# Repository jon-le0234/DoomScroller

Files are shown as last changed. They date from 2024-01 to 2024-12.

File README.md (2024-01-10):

# DoomScroller
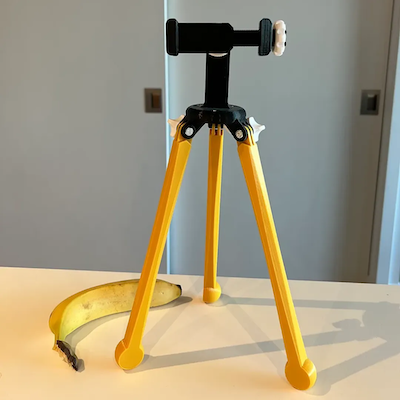
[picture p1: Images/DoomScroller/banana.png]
DoomScroller smartphone tripod holding an iPhone Pro Max in landscape

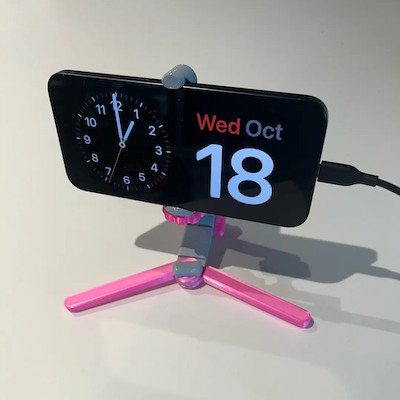
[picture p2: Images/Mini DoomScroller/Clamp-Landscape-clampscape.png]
Mini DoomScroller smartphone tripod holding an iPhone Pro Max in landscape, showing iOS 17 StandBy


A 3D-printed smartphone tripod and harm reduction tool for doomscrolling, designed with accessibility in mind.

# Overview
Originally designed for use during the COVID pandemic lockdowns, the DoomScroller and Mini DoomScroller are tripods for securely mount devices like smartphones, tablets, GoPros, and other rectangular prism objects.

[][cc-by-nc]

[][cc-by-nc]

[cc-by-nc-shield]: https://img.shields.io/badge/License-CC%20BY%204.0-lightgrey.svg
[cc-by-nc]: http://creativecommons.org/licenses/by-nc/4.0/
[cc-by-nc-image]: https://i.creativecommons.org/l/by-nc/4.0/88x31.png

## Features
1. Open source 3D model
    1. Remixed [popular, proven designs](#origin-story) on Thingiverse.
    1. Made in [OnShape CAD](https://cad.onshape.com/documents/ee0d92fdf6736f8a494244af/w/14bbf8e148085a817d797314/e/513b945eaf0116b0d17e9980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) free plan, which requires that models be shared openly.
1. Wider applications than traditional tripods and stands for electronic devices
    1. Ball joint enables wider viewing angles and orientations.
    1. Adjustable legs allow for use on uneven surfaces, such as beds, couches, and reclining chairs.
1. Portable
    1. The Mini DoomScroller folds up into a small size that can fit into a small purse, large pocket, or backpack.
1. 3D-printed
    1. Customizable design
        1. Unlike commercial, off-the-shelf smartphone tripods and stands, the DoomScroller can be printed in all your favourite colours.
        1. [Custom fastener threads](https://forum.onshape.com/discussion/4867/new-featurescript-thread-creator)
    1. Environmentally friendly
        1. Get a custom tripod without requiring a manufacturer to mass-produce and distribute a generic product.
        1. Modular design makes the DoomScroller easy to assemble, repair, and upgrade.
1. Actively developed
    1. I'm constantly pursuing a better design because I currently use the DoomScroller on a daily basis.
    1. Taking feature requests.
        1. My friend asked if I could make the DoomScroller more portable for their travels, so the Mini DoomScroller was born.
        1. GoPro functionality was requested by a user on Printables.
1. Parametric, one day
    1. Generate a custom clamp with a parametric model, once I finish the OpenSCAD design.

## Use Cases
The DoomScroller and Mini DoomScroller can be used in many applications.
1. Read social media on your smartphone in bed.
1. Watch video on your own device on a plane's tray table.
1. Join video conferencing calls like Zoom (ZoomScroller).
1. Record video where other tripods are too bulky to pack.
1. Charge your smartphone with MagSafe.
1. Use StandBy with iOS 17 on your bedside table.
1. Pair with a PanaVise [305](http://panavise.com/index.html?pageID=1&page=full&--eqskudatarq=12) or [300](http://panavise.com/index.html?pageID=1&page=full&--eqskudatarq=532) base to provide 360º horizontal rotation and 90º vertical tilt, and use with other compatible PanaVise products, like [circuit board holders](http://panavise.com/index.html?pageID=1&page=full&--eqskudatarq=24).
1. Record video on a GoPro.

Print one and give it to someone in need!

I originally hosted these two projects in Thingiverse and Printables, but it became too much work to update all four pages during active development. Thus, this documentation is meant to keep me on track. I hope that moving to Github will also make it easier for future users who can't make sense of my incomplete instructions across the original project pages.

## What is doomscrolling?
[Doomscrolling](https://en.wikipedia.org/wiki/Doomscrolling), or doomsurfing, is the act of spending an excessive amount of screen time devoted to the absorption of negative news.

I took a harm reduction approach. People are probably going to be doomscrolling anyways, so you may as well try to keep yourself safe while you're at it. No need to hurt your hands, neck, or eyes if you don't have to.

## Origin Story
During one of several COVID-19 lockdowns in 2020, I started to feel some strain in my hands and neck from scrolling all of the social media timelines on my smartphone. There was nowhere to go, nobody to visit, vaccines still being developed, all a person could do during the winter months was to escape into their smartphone for work and personal reasons.

There were already some fine mounting and tripod projects on Thingiverse, so I remixed them.
- [Tripod Phone Stand (no screw ! )](https://www.thingiverse.com/thing:4694593)
- [Modular Mounting System](https://www.thingiverse.com/thing:2194278)
- [Open Source Universal Ball Joint (to reuse!)](https://www.thingiverse.com/thing:4739696)

# Getting Started
Choose your style of DoomScroller:
1. [DoomScroller](#1-doomscroller)
1. [Mini DoomScroller](#2-mini-doomscroller)

Here is a brief comparison of the tradeoffs:
| Feature | DoomScroller | Mini DoomScroller |
| --- | --- | --- |
| Edition | Original | Newer |
| Location | Home | Data |
| Size | Bigger | Smaller |
| Materials | Plastic and metal | Plastic |
| Print Time (Prusa MK3S) | ~6.5 hours (150 mm legs) | ~3 hours |

# 1. DoomScroller
## Print Instructions
1. Pick a length for your DoomScroller's legs.
    - Either 150 mm (file 1a) or 220 mm (file 1b).
    - I'm 5'10" (178 cm) tall, and I prefer the 220 mm legs myself.
1. Pick a mounting style.
    1. Most users will need the Frame (file 7b).
        1. Frame also requires printing of Frame lock (file 8) and Frame screw (file 9).
    1. iPhone 12 and newer may want to use the MagFace (file 7a).
        1. MagFace also requires an Apple MagSafe charger.

CAUTION: Clamping too tightly on your device can break it; apparently plastic threads can be pretty strong. I take no responsibility for broken devices, but I have designed clamps that prevent damage by limiting the amount of threading.

To get a better sense of the smartphone use case, I made a table of physical dimensions of popular smartphones (Device sizes.csv). Still a work in progress, but sharing if it'll be useful to others.

### Non-3D-Printed Parts Required
1. Three (3) of M3x8 mm socket head cap screws
1. Three (3) of M3 hex nuts
1. Three (3) of M5x20mm hex bolt
1. Three (3) of M5 hex nuts

## Colour Schemes
You can do whatever you want here, truly, but files are organized for a two-tone colourway.
1. Dominant colours
    1. Legs (1ab)
    1. Hip (2)
    1. Neck (3)
    1. Ball Joint split (5)
    1. MagFace (7a)
    or
    1. Frame base (7b)
        1. Frame lock (8)
1. Accent colours
    1. Knob (4)
    1. Ball Joint screw (6)
    1. Frame screw (7b).

### Logos
Consider how many colours are used and how much area each one takes in the overall image. Usually there will be one or two dominant colours, and then some accent colours. You can even get different colours for the screws and nuts.
- Dominant colours: Legs, Neck, Hip, Frame Base, Frame Lock.
- Accent colours: Hip, Knob, Ball Joint Screw, Frame Screw, metal screws.

See the example photo of the Edmonton Oilers' McDavid jersey with an older prototype I made for a friend. I got lucky with this logo because of the oil derrick structure and orange oil drop look created by the ball joint.

## DoomScroller Assembly
See DoomScroller/Images/##.webp for visual assembly instructions.

# 2. Mini DoomScroller
## Print Instructions
Users have a few options for simple or semi-custom prints:
1. Mounting style
1. Amount of threading
1. Device width
1. Device depth

### Simple
1. Open plate file in PrusaSlicer as project to preserve the painted-on support settings.
    1. Mini DoomScroller - Clamp - Full Plate w100 x d15.3mf
    1. Mini DoomScroller - Clamp - Accent Colour.3mf
1. [Assemble](#mini-doomscroller-assembly).

### Semi-Custom
1. Select mounting style.
    1. MagFace
    1. GoPro
    1. Clamp
1. Assemble.

For clamp mounting, decide whether you want a general or single size.
1. General size
    1. Uses a longer thread, allowing for devices of multiple widths and depths.
    1. Good for using DoomScrollers with devices of different sizes, e.g., sharing with other users.
1. Single size
    1. Has a shorter thread, allowing for devices of fewer widths and depths.
    1. Good for preventing damage to devices.
    1. Good for personal use and sharing with other devices of similar size.
    1. Currently only some combinations of widths and depths are available.
1. I'm working on a parametric OpenSCAD model for the clamp. Not ready yet.
    1. This model will allow for even further customization, such as with the Thingiverse Customizer.
        
## Mini DoomScroller Assembly
See "Mini DoomScroller/Images/##.webp" files to follow along with assembly instructions.

2024-01-02: Filenames in below instructions need to be updated.

1. Insert torso.3mf and neck.3mf so that hinges are flush on both sides.
1. Insert hip-bolt.3mf into the unthreaded side of the hinge, then screw into the M12 thread of neck.3mf to tighten hinge.
1. Place ball.3mf into the spherical section in neck.3mf.
1. Place ball-joint-nut.3mf over ball.3mf, and screw onto the M22 thread of neck.3mf to tighten.
1. Screw the selected mount into the M12 thread of ball.3mf.
1. If using magface.3mf, skip to step 9.
1. Insert clamp-movable-jaw.3mf over clamp-frame.3mf.
1. Screw clamp-nut.3mf onto the M15 thread of Clamp frame.3mf.
1. Place left-leg-threaded.3mf on the underside of the joint on torso.3mf. It will sit between torso.3mf and neck.3mf when folded.
1. Place right-leg.3mf on the opposite side of the torso joint.
1. (Optional) Use leg-bolt-washer.3mf on top of right-leg.3mf. This adds length for leg-bolt.3mf, and adds another option for mixing colours.
1. Insert leg-bolt.3mf through right-leg.3mf and screw into M12 thread of left-leg.3mf.
1. It is finished! 

## Print Recommendations
### Colours
You can choose whichever colour scheme you like! I’ve printed Mini DoomScrollers in monochrome, two-tone, and rainbow.

Found the two-tone to be received best by beta testers, so I’ve organized the files into folders “Main Colour” and “Accent Colour.”

### Materials
PLA and PETG work great!

PETG is a little bouncier.

## Supports
I set the following PrusaSlicer settings for easier removal of supports (see screenshot in gallery):

1. Snug for “Style” is better than Organic for this model.
1. 90º for “Pattern angle” exposes the snug supports' folds.
1. 0.3 mm for both “Top contact Z distance” and “Bottom contact Z distance.
1. 2 layers for both “Top interface layers” and “Bottom interface layers.”

## Additional Considerations
1. OnShape link for intrepid users that want to customize the design further: [Mini DoomScroller](https://cad.onshape.com/documents/ee0d92fdf6736f8a494244af/w/14bbf8e148085a817d797314/e/513b945eaf0116b0d17e9980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)
    1. Requires an OnShape account.
    1. Create a copy of the design.
    1. Customize to your heart's content.
1. Ball joint uses an M12 thread with 1.5 mm pitch.
1. Clamp screw, hip bolt, and leg bolt use an M15 thread with 1.5 mm pitch.

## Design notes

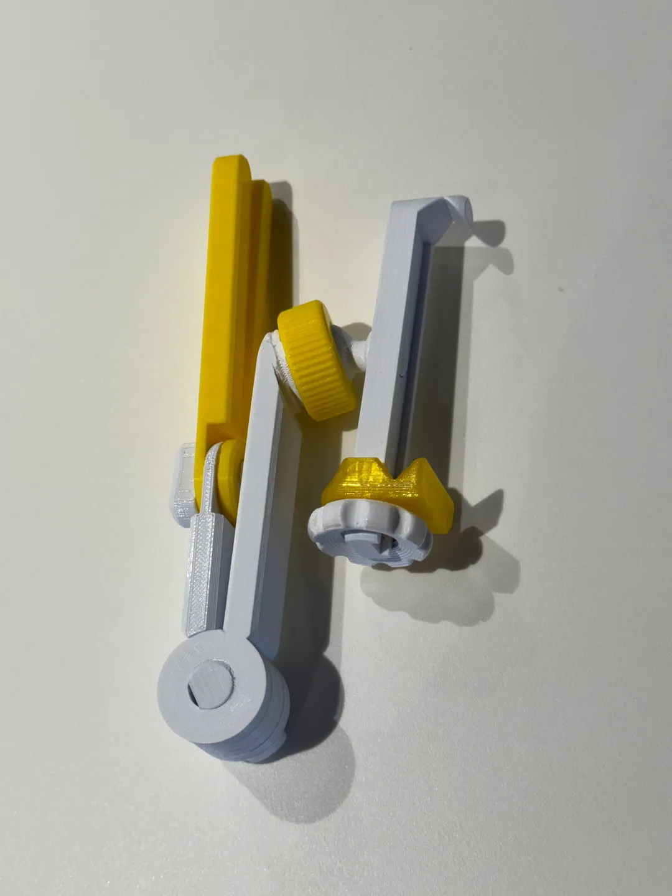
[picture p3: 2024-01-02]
Images/Mini DoomScroller/clamp-folded.png

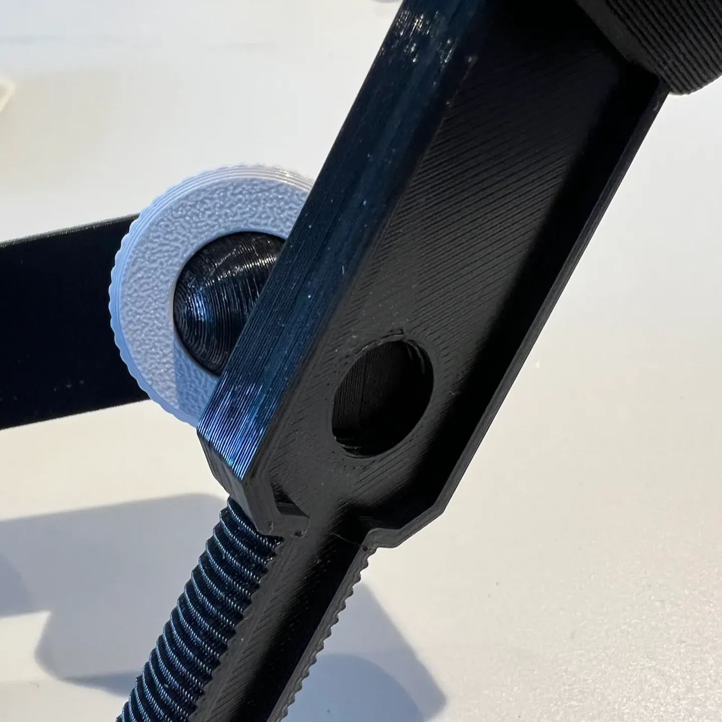
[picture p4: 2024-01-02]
Images/DoomScroller/15b.png

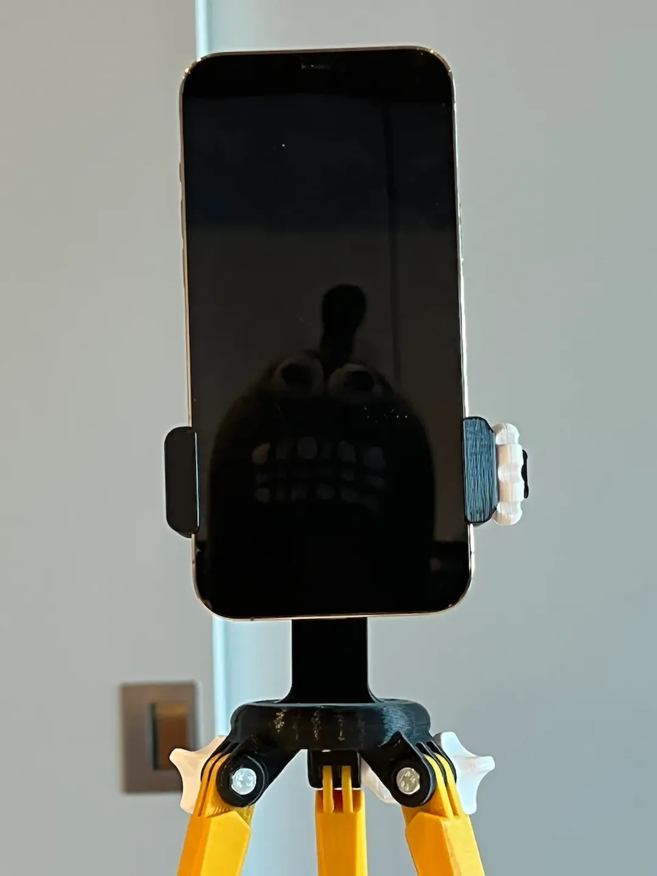
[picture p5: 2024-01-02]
Images/DoomScroller/portrait.png

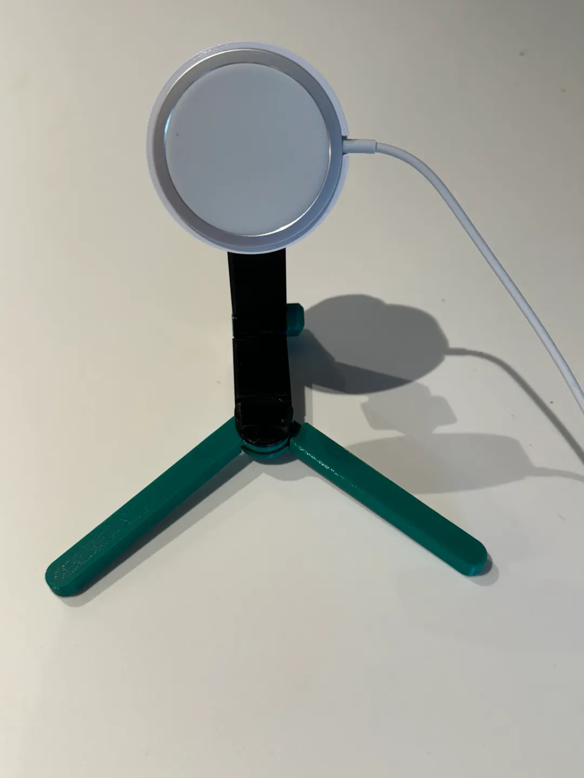
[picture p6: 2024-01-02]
Images/Mini DoomScroller/magface.png

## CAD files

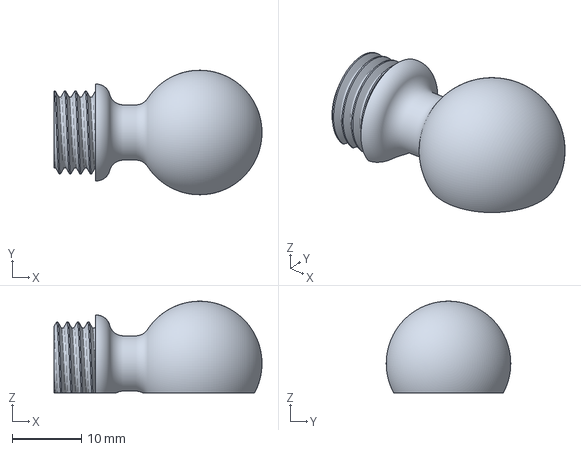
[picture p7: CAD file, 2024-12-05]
3D-Models/Ball.3mf
30.1 x 18.0 x 13.2 mm

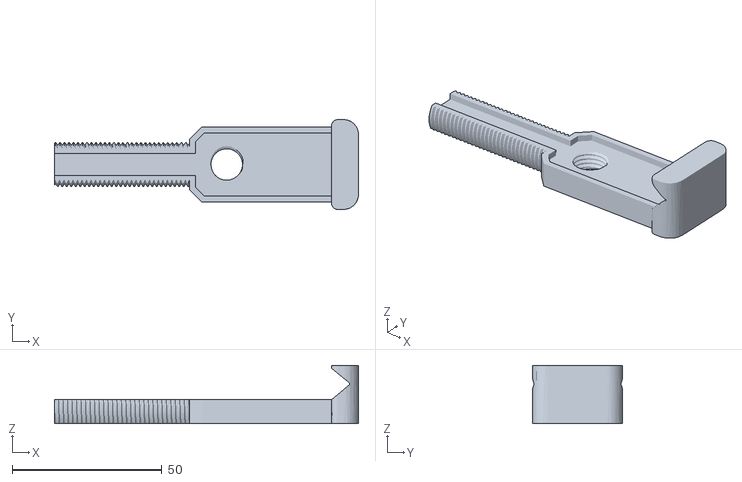
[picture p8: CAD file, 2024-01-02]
3D-Models/Common-Components/Mounts/Clamps/7c DoomScroller - Frame base (original).stl
101.5 x 30.0 x 19.5

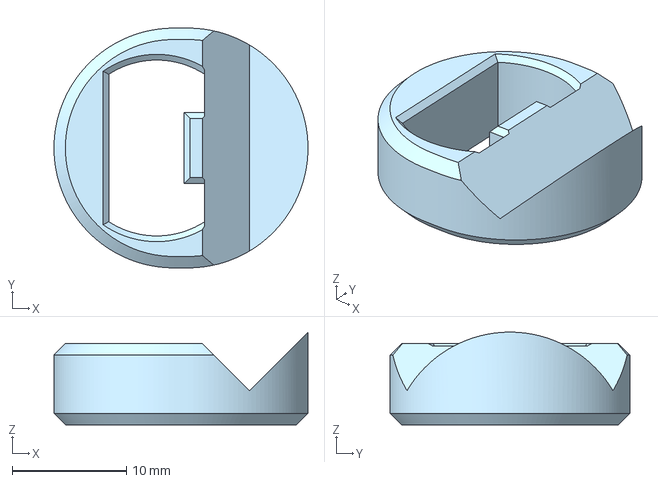
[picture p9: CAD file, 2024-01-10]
3D-Models/Common-Components/Mounts/Clamps/Smartphones/Mini DoomScroller - Clamp movable jaw iPhone 15 Pro Max.3mf
22.2 x 21.0 x 8.12 mm

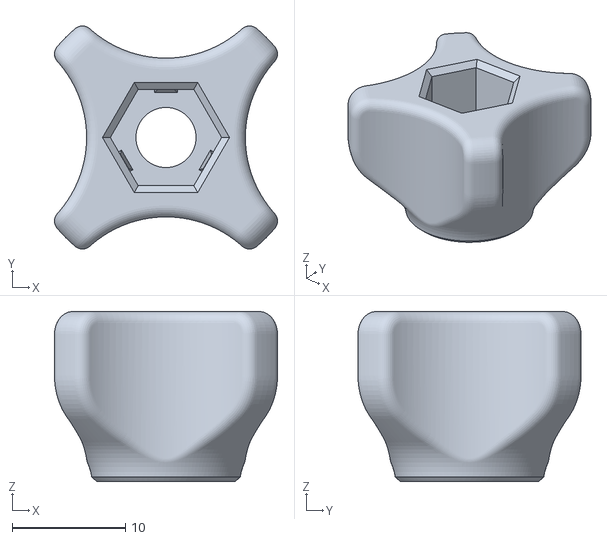
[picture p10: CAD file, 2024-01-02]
3D-Models/DoomScroller/DoomScroller - Knob.stl
19.7 x 19.7 x 15.0

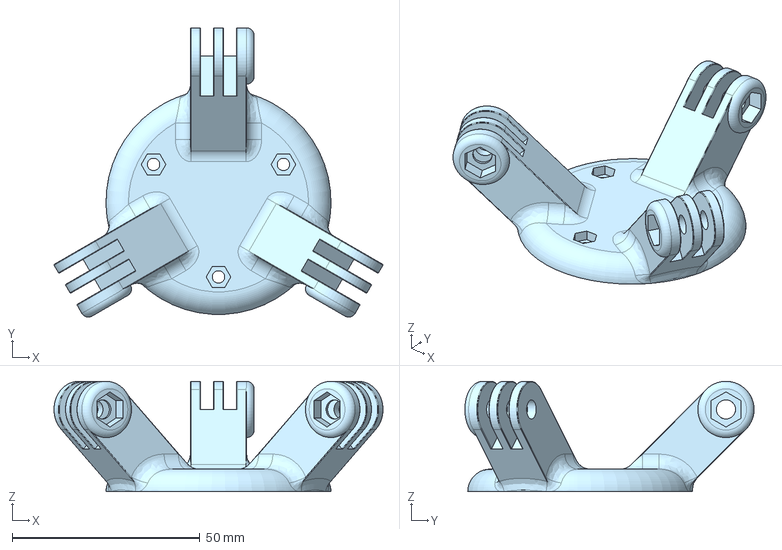
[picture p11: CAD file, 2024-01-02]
3D-Models/DoomScroller/Hips/2a DoomScroller - Hip.step
87.7 x 77.1 x 29.4 mm

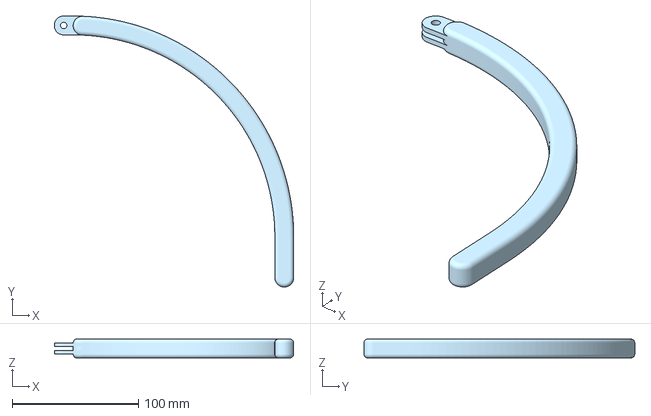
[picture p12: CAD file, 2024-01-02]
3D-Models/DoomScroller/Legs/1d DoomScroller - Leg, Curved 160 + 40.3mf
190.0 x 215.0 x 15.0 mm

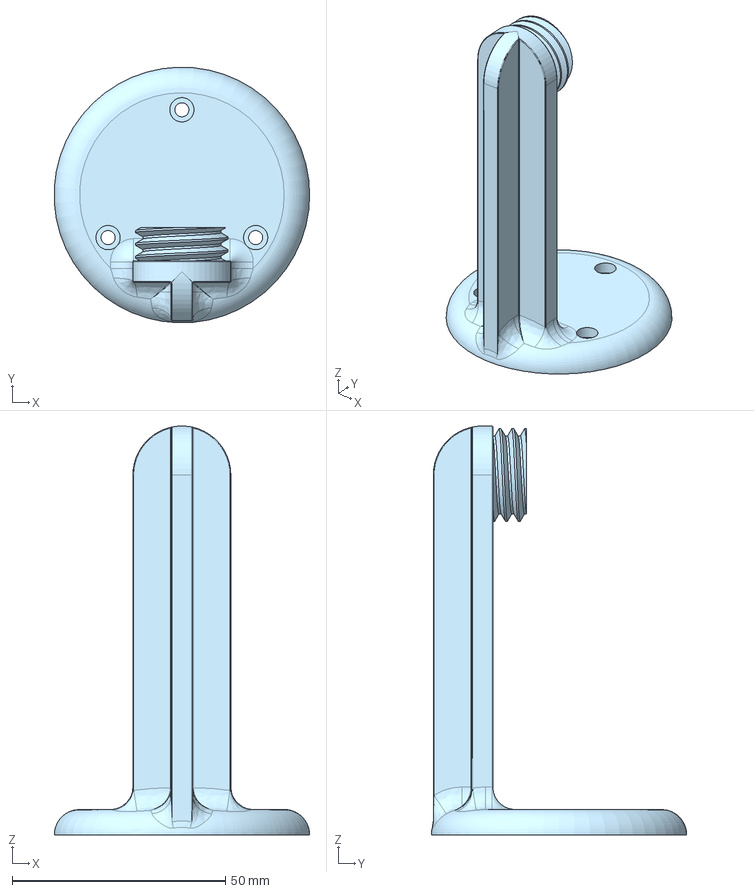
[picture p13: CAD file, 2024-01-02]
3D-Models/DoomScroller/Necks/3a DoomScroller - Neck.step
59.9 x 60.0 x 96.0 mm

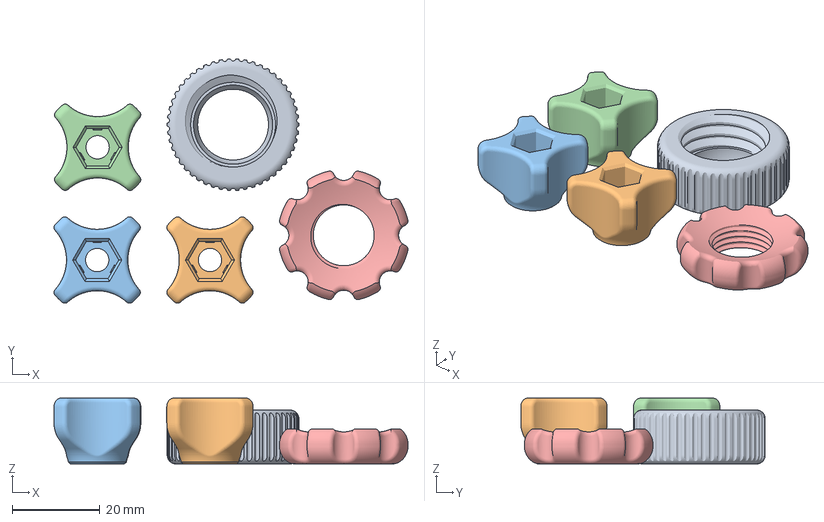
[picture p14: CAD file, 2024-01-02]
3D-Models/DoomScroller/Plates/DoomScroller-Accent-Colour.3mf
80.6 x 55.6 x 15.0 mm
6 DoomScroller - Ball Joint Screw.stl
4 DoomScroller - Knob.stl
9 DoomScroller - Frame screw.stl

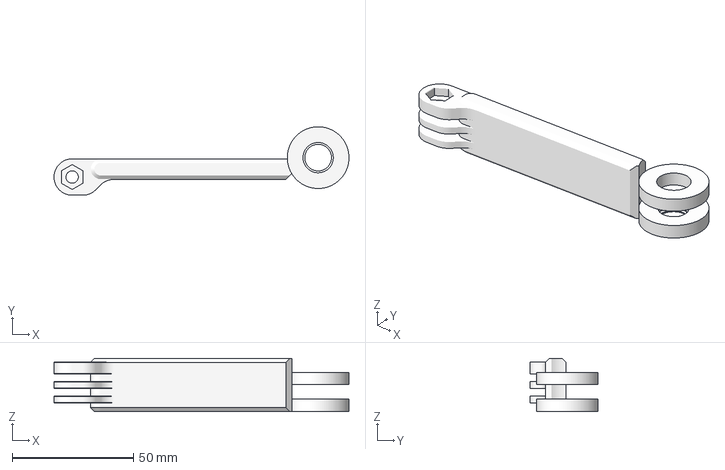
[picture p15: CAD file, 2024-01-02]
3D-Models/Mini DoomScroller/Alternate Designs/Neck-GoPro.3mf
121.7 x 28.2 x 22.0 mm

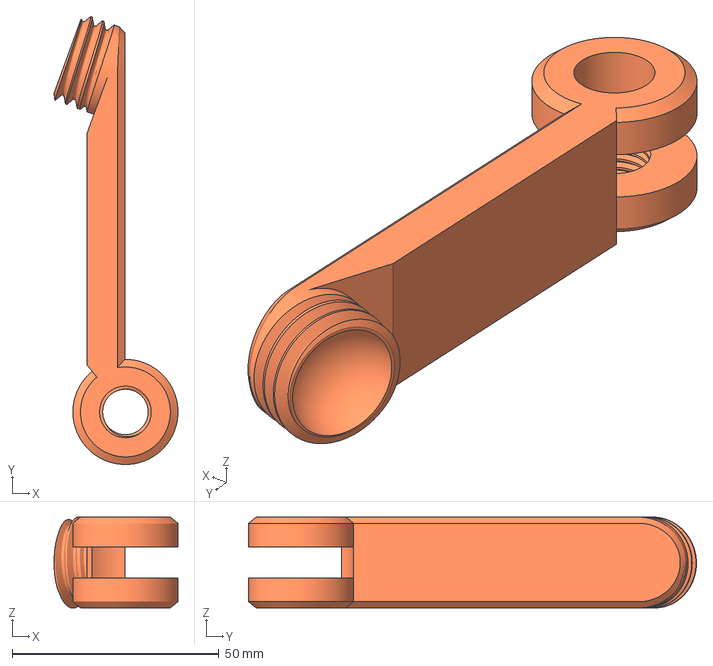
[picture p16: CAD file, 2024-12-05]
3D-Models/Mini DoomScroller/Mini DoomScroller - Neck.3mf
30.0 x 108.5 x 22.0 mm

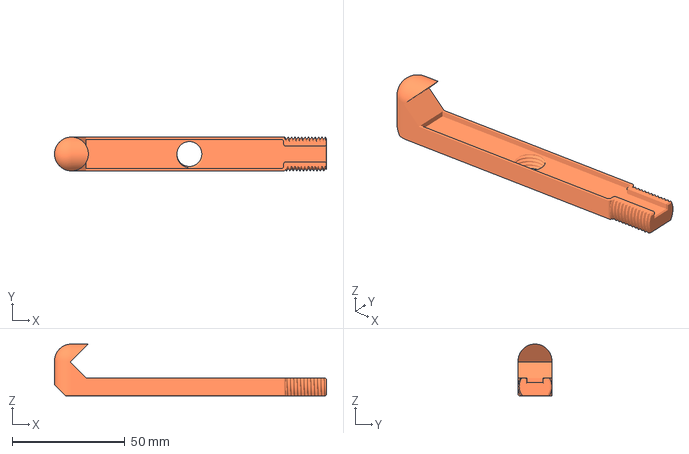
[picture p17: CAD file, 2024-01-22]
3D-Models/Mounts/Clamps/Game Console/Nintendo Switch Lite/DoomScroller - Clamp frame-Nintendo Switch Lite.3mf
120.5 x 15.0 x 23.0 mm

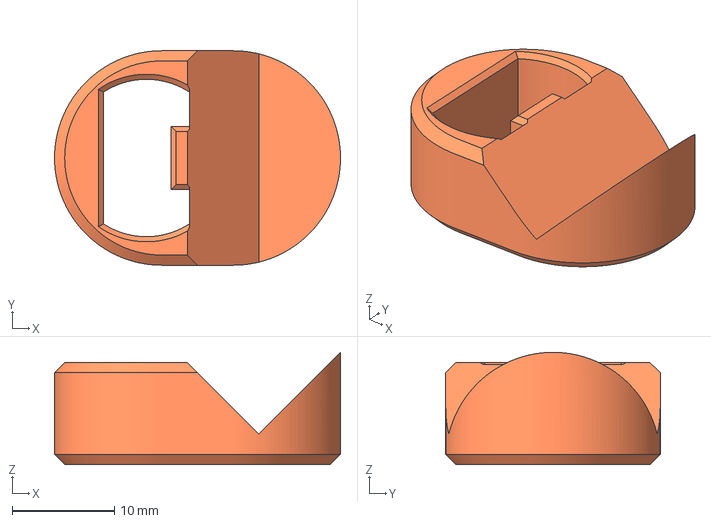
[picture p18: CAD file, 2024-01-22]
3D-Models/Mounts/Clamps/Game Console/Nintendo Switch OLED/DoomScroller - Clamp movable jaw-Nintendo Switch OLED.3mf
28.0 x 21.0 x 11.0 mm

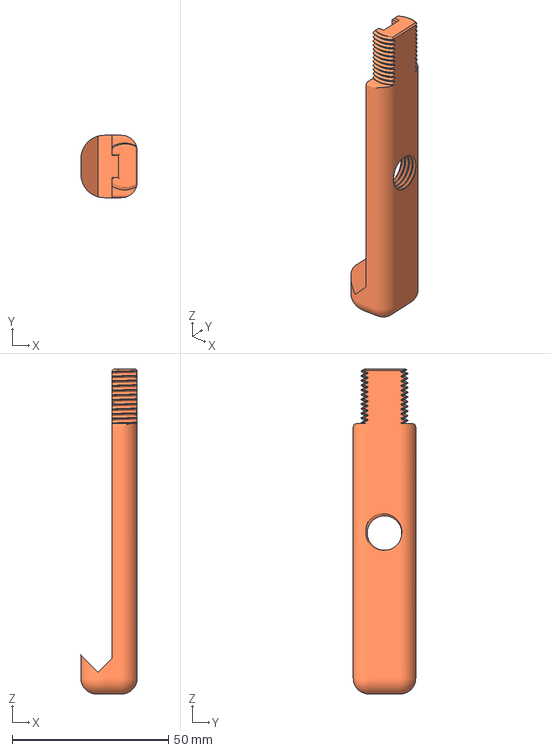
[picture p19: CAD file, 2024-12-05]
3D-Models/Mounts/Clamps/General Smartphone/Caseless/DoomScroller - Clamp frame-Smartphone 9-80-5.3mf
18.0 x 20.0 x 104.0 mm

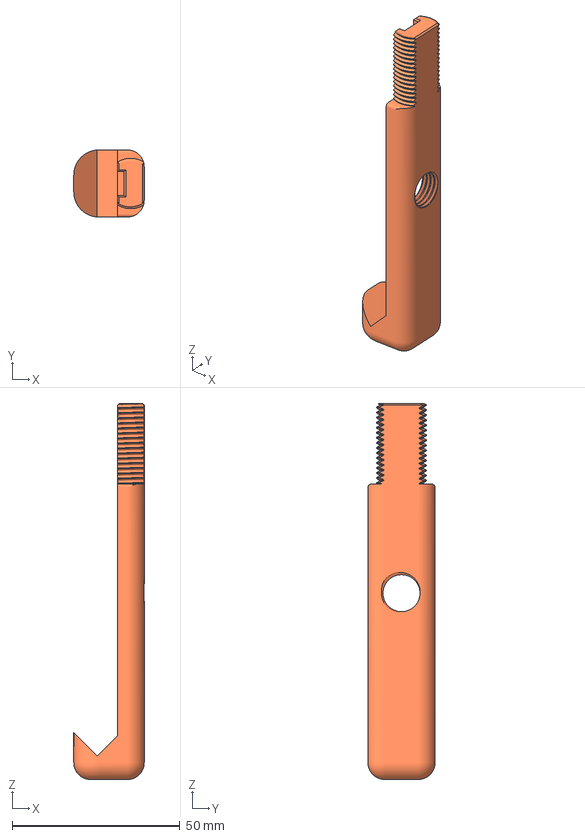
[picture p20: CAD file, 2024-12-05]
3D-Models/Mounts/Clamps/General Smartphone/Encased/DoomScroller - Clamp frame-Smartphone case 12-85-10.3mf
21.0 x 20.0 x 112.0 mm

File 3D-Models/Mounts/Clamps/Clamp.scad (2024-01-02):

use <quickthread.scad>

// Comments structure:
// HEADING 1
// Heading 2
// heading 3

// TABLE OF CONTENTS
// OVERVIEW
    // Purpose
// VARIABLES
    // Parametric variables 
    // Optional variables 
    // Constants
// POLYGONS

// OVERVIEW

// Purpose
// Parametric model for the DoomScroller clamp
// https://www.printables.com/model/569377-the-mini-doomscroller-a-portable-smartphone-tripod
// Finally crumbled and was forced to learn OpenSCAD for a model that needed to be parameterized.

// VARIABLES

// 1. Parametric Variables

// device_width
device_width = 80;
device_height = 10;
// using "_height" to align with OpenSCAD's use of height for Z-axis
// normally would refer to it as device_depth when device is facing you and Z-axis travels through the screen, but that would be too confusing here
device_depth = 160;

// Optional Variables

// distance to determine strength of adhesion keep clamp frame's left-top prism adhered to left-bottom prism
prism_connector_width = 7;

// distance for clamp left-top prism to hang over the device bezel
bezel_overhang = 2;

// CONSTANTS

// clamp frame
clamp_frame_base_height = 8;
clamp_frame_base_depth = 15;

// clamp screw
clamp_nut = 8;

// clamp screw distance 
// SAFETY FIRST: adding more than 2 mm to 3 mm of clamping distance means you could crush a device
clamp_screw_distance = 2;

// clamp movable jaw
clamp_movable_jaw_cube_x = 3;
clamp_movable_jaw_cube_y = 25;
clamp_movable_jaw_cube_z = 25;

// clamp movable jaw key
// would normally define closer to the 
clamp_movable_jaw_key_cube_y = 7;
clamp_movable_jaw_key_cube_z = 2;

// overlap factor for joining OpenSCAD objects
overlap = 0.001;

// POLYGONS

// Polygon dimensions are defined just above the polygon functions. Then translation units are listed below them.
// That makes it easier to locate and edit the variables.
// Also makes the code much more verbose, but this is also my first major OpenSCAD project.

// Device
device_cube_x = device_width;
device_cube_y = device_depth;
device_cube_z = device_height;

device_cube_translation_y = -device_depth/2 + clamp_frame_base_depth/2;
device_cube_translation_z = clamp_frame_base_height;

//translate([0,device_cube_translation_y,device_cube_translation_z]) cube([device_cube_x, device_cube_y, device_cube_z]);

// Clamp Frame

// clamp frame base
base_cube_x = device_width - clamp_screw_distance;
base_cube_y = clamp_frame_base_depth;
base_cube_z = clamp_frame_base_height;

// cube to reduce print of clamp base
clamp_base_reduce_cube_x = base_cube_x - 1;
clamp_base_reduce_cube_y = base_cube_y - 2;
clamp_base_reduce_cube_z = 2 + overlap;

clamp_base_reduce_cube_translate_y = 1;
clamp_base_reduce_cube_translate_z = 6;

// cube to create opening between clamp base border and screw key
clamp_base_border_key_cube_x = 1 + 2*overlap;
clamp_base_border_key_cube_y = clamp_movable_jaw_key_cube_y;
clamp_base_border_key_cube_z = clamp_movable_jaw_key_cube_z + 2*overlap;

clamp_base_border_key_cube_translate_x = base_cube_x - 1 - overlap;
clamp_base_border_key_cube_translate_y = clamp_frame_base_depth/2 - clamp_base_border_key_cube_y/2;
clamp_base_border_key_cube_translate_z = 6;

// subtract clamp_base_reduce from clamp_base
difference() {
cube([base_cube_x, base_cube_y, base_cube_z]);
    // print reduction
translate([0, clamp_base_reduce_cube_translate_y, clamp_base_reduce_cube_translate_z]) cube([clamp_base_reduce_cube_x, clamp_base_reduce_cube_y, clamp_base_reduce_cube_z]);
    // border-key opening
translate([clamp_base_border_key_cube_translate_x, clamp_base_border_key_cube_translate_y, clamp_base_border_key_cube_translate_z]) cube([clamp_base_border_key_cube_x, clamp_base_border_key_cube_y, clamp_base_border_key_cube_z]);
}

// prism module taken from user manual:
// https://en.wikibooks.org/wiki/OpenSCAD_User_Manual/Primitive_Solids#polyhedron
// modified variables to better represent how it will appear
module prism(x, y, z){
      polyhedron(//pt 0        1        2        3        4        5
              points=[[0,0,0], [x,0,0], [x,y,0], [0,y,0], [0,y,z], [x,y,z]],
              faces=[[0,1,2,3],[5,4,3,2],[0,4,5,1],[0,3,4],[5,2,1]]
              );
      }

// left-bottom prism of clamp frame
// translated to left side of clamp frame cube, then rotated 90º about Z-axis
// rotating then translating makes for trouble
left_bottom_prism_x = clamp_frame_base_depth;
left_bottom_prism_y = device_height/2;
left_bottom_prism_z = device_height/2 + 1;
      
left_bottom_prism_translate_z = clamp_frame_base_height;

translate([0, 0, left_bottom_prism_translate_z]) rotate([0, 0, 90]) prism(left_bottom_prism_x, left_bottom_prism_y, left_bottom_prism_z);

// left-top prism of clamp frame
// translated to left side of clamp frame cube, then rotated 90º about X- and Z-axes
left_top_prism_x = clamp_frame_base_depth;
left_top_prism_y = device_height/2 + 1;
left_top_prism_z = device_height/2 + bezel_overhang;

left_top_prism_translate_x = -device_height/2;
left_top_prism_translate_z = clamp_frame_base_height + left_bottom_prism_z;

translate([left_top_prism_translate_x, 0, left_top_prism_translate_z]) rotate([90,0,90]) prism(left_top_prism_x, left_top_prism_y, left_top_prism_z);

// cube to join clamp base and left-bottom prism
cube_base_prism_x = device_height/2 + overlap;
cube_base_prism_y = clamp_frame_base_depth;
cube_base_prism_z = clamp_frame_base_height + overlap;

cube_base_prism_translate_x = cube_base_prism_x - overlap;

translate([-cube_base_prism_translate_x, 0, 0]) cube([cube_base_prism_x, cube_base_prism_y, cube_base_prism_z]);

// cube to define clamp frame prisms' adhesions area
// also join clamp left-bottom and left-top prisms
left_prisms_cube_x = prism_connector_width + overlap;
left_prisms_cube_y = clamp_frame_base_depth;
left_prisms_cube_z = clamp_frame_base_height + left_bottom_prism_z + left_top_prism_y;

cube_left_prisms_translate_x = left_prisms_cube_x + left_bottom_prism_y - overlap;

translate([-cube_left_prisms_translate_x, 0, 0]) cube([left_prisms_cube_x, left_prisms_cube_y, left_prisms_cube_z]);

// Clamp screw

// screw
screw_diameter = 15;
screw_length = clamp_screw_distance + clamp_movable_jaw_cube_x + clamp_nut + overlap;
screw_pitch = 1.5;

screw_translate_x = base_cube_x - overlap;
screw_translate_y = clamp_frame_base_depth/2;
screw_translate_z = (device_height-2)/2;

// screw flattening top
screw_flat_top_cube_x = screw_diameter/2 - 4;
screw_flat_top_cube_y = screw_diameter;
screw_flat_top_cube_z = screw_length + 2*overlap;

screw_flat_top_cube_translate_x = 4;
screw_flat_top_cube_translate_y = -screw_diameter/2;
screw_flat_top_cube_translate_z = -overlap;

// screw flattening bottom
screw_flat_bottom_cube_x = screw_diameter/2 - 4;
screw_flat_bottom_cube_y = screw_diameter;
screw_flat_bottom_cube_z = screw_length + 2*overlap;

screw_flat_bottom_cube_translate_x = 4;
screw_flat_bottom_cube_translate_y = -screw_diameter/2;
screw_flat_bottom_cube_translate_z = -overlap;

// screw key
// mixing z and x because of order of operations required for translation and rotation later
screw_key_cube_x = clamp_movable_jaw_key_cube_z + overlap;
screw_key_cube_y = clamp_movable_jaw_key_cube_y;
screw_key_cube_z = screw_length + 2*overlap;

screw_key_cube_translate_x = -4 - overlap;
screw_key_cube_translate_y = -screw_key_cube_y/2;
screw_key_cube_translate_z = -overlap;

translate([screw_translate_x, screw_translate_y, screw_translate_z]) rotate([0, 90, 0]) 
difference() {
isoThread(d = screw_diameter, h = screw_length, pitch = screw_pitch, angle=40, internal=false,$fn=60);
translate([screw_flat_top_cube_translate_x, screw_flat_top_cube_translate_y, screw_flat_top_cube_translate_z]) cube([screw_flat_top_cube_x, screw_flat_top_cube_y, screw_flat_top_cube_z]);
mirror([1, 0, 0])
translate([screw_flat_bottom_cube_translate_x, screw_flat_bottom_cube_translate_y, screw_flat_bottom_cube_translate_z]) cube([screw_flat_bottom_cube_x, screw_flat_bottom_cube_y, screw_flat_bottom_cube_z]);
translate([screw_key_cube_translate_x, screw_key_cube_translate_y, screw_key_cube_translate_z]) cube([screw_key_cube_x, screw_key_cube_y, screw_key_cube_z]);

}
//

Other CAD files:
3D-Models/Mounts/Clamps/Game Console/Nintendo Switch/DoomScroller - Clamp movable jaw-Nintendo Switch.3mf
3D-Models/Mounts/Clamps/Smartphone Models/Galaxy Note 10+/DoomScroller - Clamp frame-Galaxy Note 10+.3mf
3D-Models/Mounts/Clamps/Smartphone Models/Galaxy Note 10/DoomScroller - Clamp movable jaw-Galaxy Note 10.3mf
3D-Models/Mounts/Clamps/Smartphone Models/Galaxy S20 Ultra 5G/DoomScroller - Clamp frame-Galaxy S20 Ultra 5G.3mf
3D-Models/Ball joint nut.stl
3D-Models/Clamp nut.stl
3D-Models/Common-Components/Mounts/Clamps/Smartphones/7d DoomScroller - Frame base for iPhone Pro Max.stl
3D-Models/Common-Components/Mounts/Clamps/Smartphones/7e DoomScroller - Frame base for iPhone mini.stl
3D-Models/Common-Components/Mounts/Clamps/Smartphones/Mini DoomScroller - Clamp frame iPhone 15 Pro Max.3mf
3D-Models/DoomScroller/Hips/2b DoomScroller Hip - PanaVise 300 305.3mf
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

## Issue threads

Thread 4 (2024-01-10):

Clamps directory is a mess

jon-le0234, 2024-01-10:
Clamps directory needs to be organized to make it easier for people to pick the one or two files they need from it.

Couple ideas:
1. Organize by device type, e.g., smartphone, tablet.
2. Add section for cases.
3. Highlight existing parametric option in README by using OnShape.
4. Adding more plates.

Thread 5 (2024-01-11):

Replace fastener from the ball joint

jon-le0234, 2024-01-11:
M12 thread from ball joint is nice and all, but rotating a device counter-clockwise loosens it. Need to come up with an alternate system to pair the two subsystems.

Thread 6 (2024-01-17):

Left leg can be modified to print flat with no supports

jon-le0234, 2024-01-17:
The original purpose of design threaded left, leg, minimize overall volume. However, it’s probably better for print stability to rotate it 180° and print without supports.

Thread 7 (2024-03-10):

Clamp fixed jaw is uncomfortable against hand in long term use

jon-le0234, 2024-03-10:
The chamfer along the bottom edge of the clamp’s fixed jaw, as oriented when printing, is too sharp a vertex against my hand in real world usage. Something needs to be improved for physical comfort.

Generally, the Mini DoomScroller benefits from miniaturization compared to the DoomScroller, but there are plenty of quality of life improvements that can aid in printing and use. This version of the clamp is certainly smaller and faster to print than the original, but it is worse in comfort for even short term use.

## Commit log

2024-01-02 Update README.md
    Added description from Printables.com
2024-01-02 Initial upload of print files
    [1a DoomScroller - Leg 150.step, 1a DoomScroller - Leg 150.stl, 1b DoomScroller - Leg 220.stl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]
2024-01-02 Directories
    Created directories for files
    [1a DoomScroller - Leg 150.step, 1a DoomScroller - Leg 150.stl, 1b DoomScroller - Leg 220.stl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]
2024-01-02 Initial upload of Mini DoomScroller.
    [1a DoomScroller - Leg 150.step, 1a DoomScroller - Leg 150.stl, 1b DoomScroller - Leg 220.stl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]
2024-01-02 Fixed Mini DoomSCroller image, removed spaces from directories and filenames, formatted features
    [1a DoomScroller - Leg 150.step, 1a DoomScroller - Leg 150.stl, 1b DoomScroller - Leg 220.stl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]
2024-01-02 Updated PanaVise use case, Mini DoomScroller assembly, OnShape link. Moved licence up.
2024-01-02 Moved Mini DoomScroller 3D models into subdirectory, replaced Mini DoomScroller's ball joint nut file
    Moved 3D model files into subdirectory "3D-Models" to match DoomScroller layout.
    Replaced Mini DoomScroller's "Ball joint screw.stl" with correct model with coarse threads. Renamed "Ball-joint-nut.stl."
    [Ball joint screw.stl, Ball-joint-nut.stl, Ball.3mf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]
2024-01-02 Add two files for clamp d15
    75 mm and 80 mm widths
    [Clamp-frame-w75-d15.3mf, Clamp-frame-w80-d15.3mf]
2024-01-02 Corrected year in Mini DoomScroller Assembly
2024-01-03 Clamp movable jaw key 0.2 mm
    Smaller clearance on clamp movable jaw's key of 0.2 mm.
    Changed design to be relative to Clamp frame.
    [Clamp-movable-jaw-d10.3mf, Clamp-movable-jaw-d15.3mf, Clamp-movable-jaw-d8.3mf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]
2024-01-03 Create MiniDS-w80-d15.3mf
    Plate for MiniDS for devices of width 80 mm and depth 15 mm
2024-01-09 Preparing for big update with semi-custom clamps
    [Clamp-frame-w100-d15-t20.3mf, Clamp-frame-w100-d15.3mf, Clamp-frame-w75-d15-t20.3mf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]
2024-01-10 Reorganized directory structure
    Merged DS and MiniDS directories into one "3D-Model" directory.
    Removed Ball joint nut with wrong pitch.
    Added new plate for iPhone 15 Pro Max.
    [1a DoomScroller - Leg 150.step, 1a DoomScroller - Leg 150.stl, 1b DoomScroller - Leg 220.stl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]
2024-01-22 Device clamps
    Big update for clamp frames and clamp movable jaws for multiple devices like iPhones, Galaxy, and Switch
    [7c DoomScroller - Frame base (original).stl, 7d DoomScroller - Frame base for iPhone Pro Max.stl, 7e DoomScroller - Frame base for iPhone mini.stl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]
2024-01-24 Reorganizing directory some more
    Trying to simplify the project so it's not so overwhelming with all the different filenames and subdirectories
    [7b DoomScroller - MagFace iPhone Pro Max.stl, 7c DoomScroller - Frame base (original).stl, 7d DoomScroller - Frame base for iPhone Pro Max.stl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]
2024-03-18 New clamp files for iPhone 15 Pro Max plate
2024-05-04 New plate for device size depth 10, width 80, thread 20
2024-05-04 Fixed support settings on plate for device size depth 10, width 80, thread 20
2024-08-19 Added some plates
    [MiniDS - General Smartphone w85 d15 t15.3mf, MiniDS - iPhone 13 Pro Max with case s10.3mf]
2024-08-20 Replaced plate for General smartphone with new naming
    Indicates thickness of device, width, and length of clamp thread
    [MiniDS - General Smartphone w85 d15 t15.3mf, MiniDS - Smartphone case 12-75-10.3mf]
2024-12-05 Preparing to finalize
    Work in progress of finalizing the Mini DoomScroller design so I can move on to a new design
    [7c DoomScroller - Frame base (original).stl, 7d DoomScroller - Frame base for iPhone Pro Max.stl, 7e DoomScroller - Frame base for iPhone mini.stl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]

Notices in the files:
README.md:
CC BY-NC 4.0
